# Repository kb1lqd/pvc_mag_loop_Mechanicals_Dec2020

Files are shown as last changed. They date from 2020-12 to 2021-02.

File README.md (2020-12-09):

# pvc_mag_loop_Mechanicals_Dec2020

This project is a work in progress as of 12-8-2020!
* Only the bottom clamp has been designed so far

This project is a FreeCAD design that is creating mounting bracket for my amateur radio magnetic loop antenna. The project implements the following sized components:

* Copper Pipe = 0.5"
* PVC Pipe = Schedule 40 2"

The design is fixed to these dimensions. Future update(s) may look to make this more scalable within FreeCAD using parametric links.

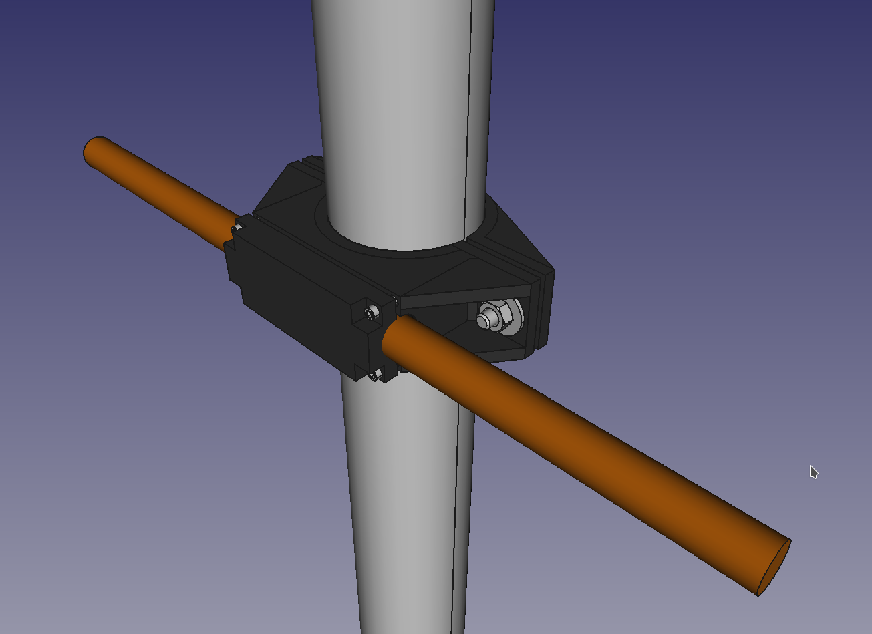
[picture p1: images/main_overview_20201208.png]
PVC to copper pipe magnetic loop adapter overview CAD image


## Known To-Do's

* Create top mount bracket
* Create capacitor mount bracket
* Create coupling loop bracket
* Update bottom clamp to show 4-40 threaded inserts
* Create BOM

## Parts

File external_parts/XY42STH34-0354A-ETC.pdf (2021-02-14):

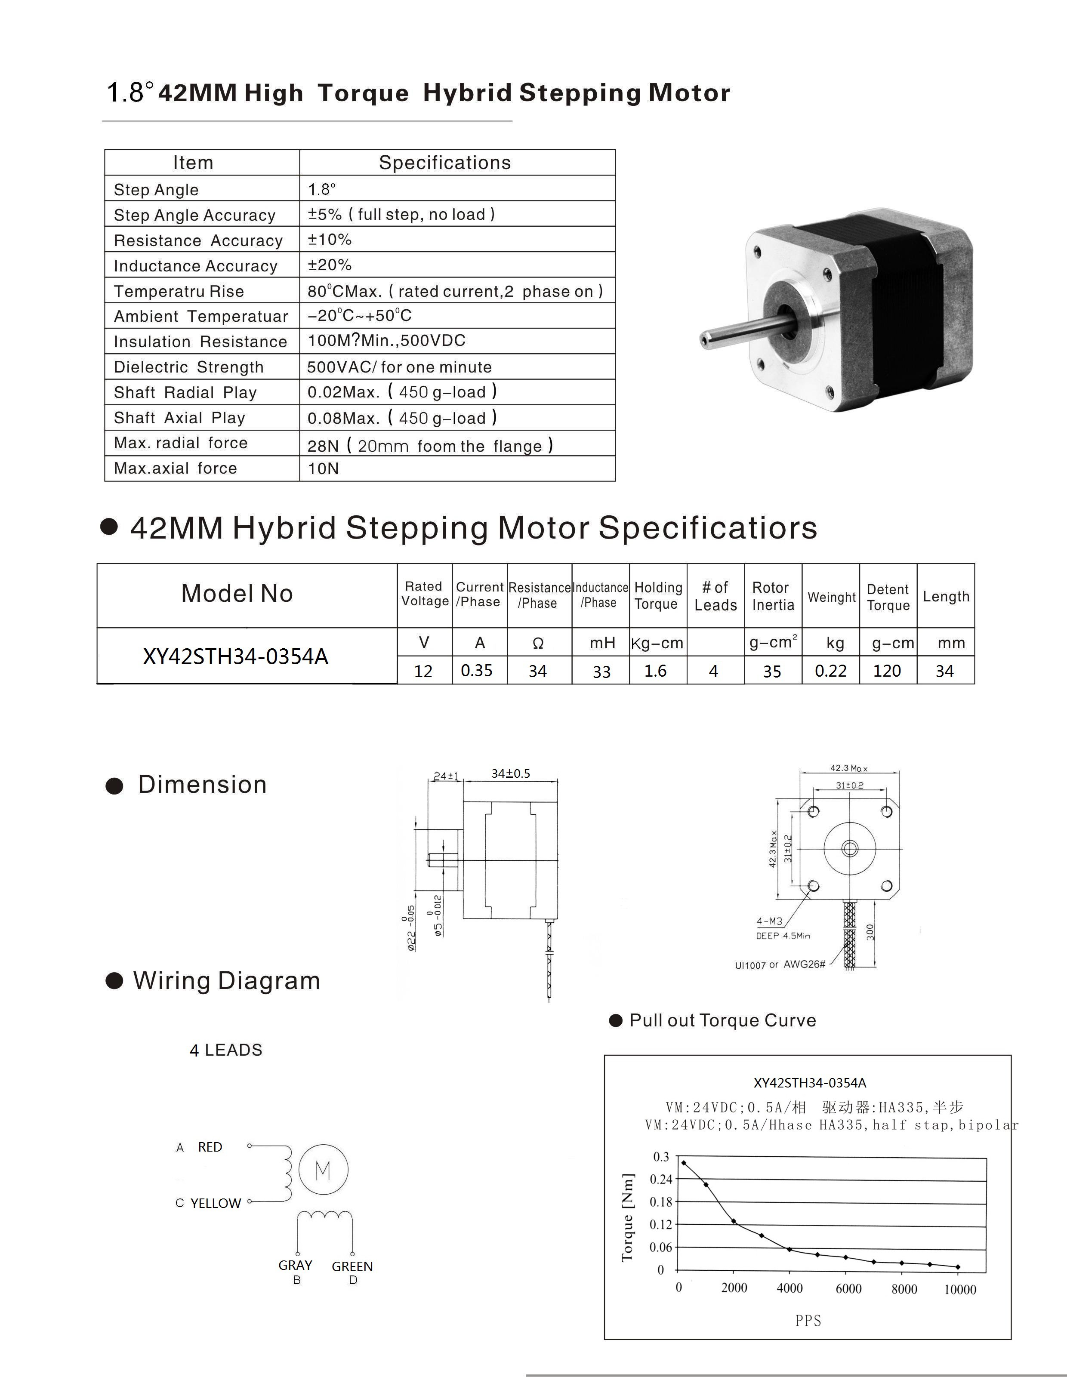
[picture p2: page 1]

07/03/2016 | C140-A datasheet.jpg (2480×3201)
https://www.adafruit.com/images/productfiles/324/C140-A%20datasheet.jpg | 1/1

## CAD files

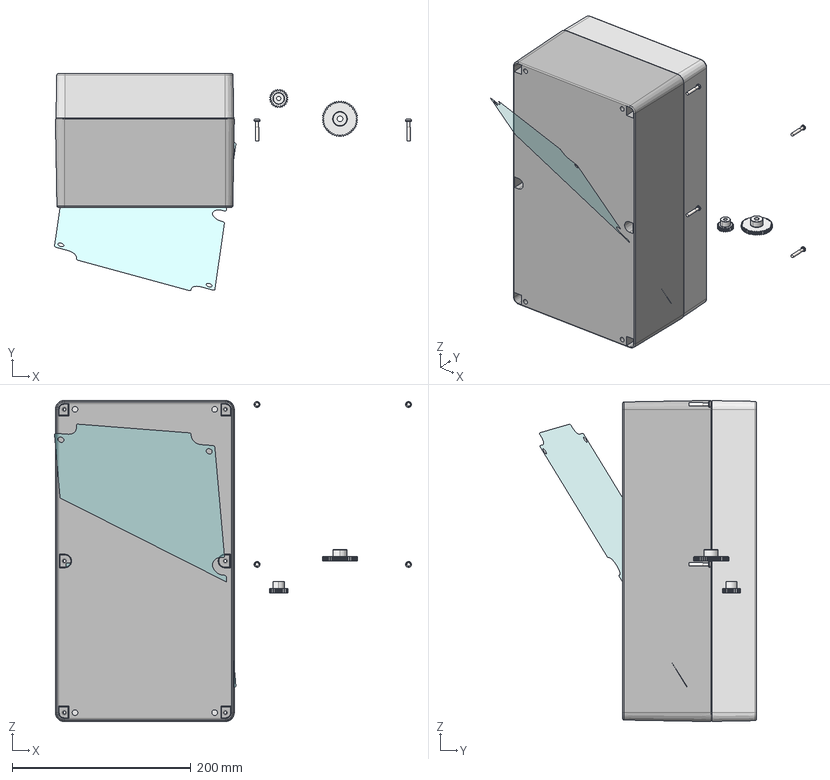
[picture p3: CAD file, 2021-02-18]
Version_3/capacitor_assembly_v1.FCStd
399.6 x 243.3 x 359.5 mm
W_-44B_WA-44B*16
SCREWS-SSM4-25
SCREWS-SSM4-026
SCREWS-SSM4-027
SCREWS-SSM4-028
SCREWS-SSM4-029
SCREWS-SSM4-030
W_-44C_WA-44C*16
W_-44B-PCB_WA-44B*16-PCB
2662N15
2662N18
_Element002
_Element003
_Element004
_Element005
_Element006
_Element007
_Element008
_Element009
_Element010
_Element011

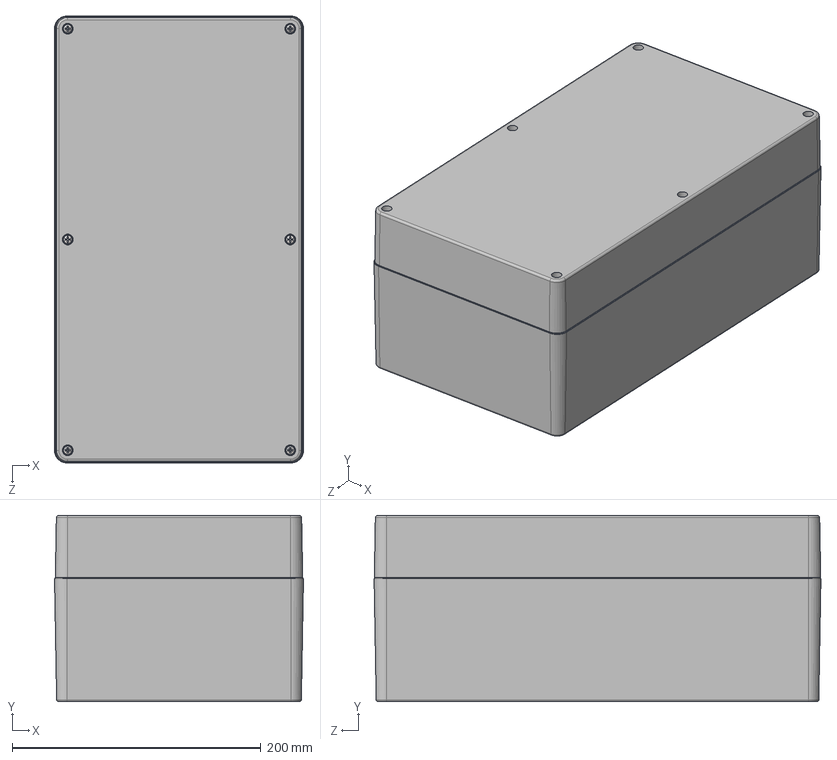
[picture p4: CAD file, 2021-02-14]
external_parts/WA-44.STEP
200.3 x 150.0 x 359.5 mm
W_-44B_WA-44B*16
SCREWS-SSM4-25 x 6
W_-44C_WA-44C*16
W_-44B-PCB_WA-44B*16-PCB

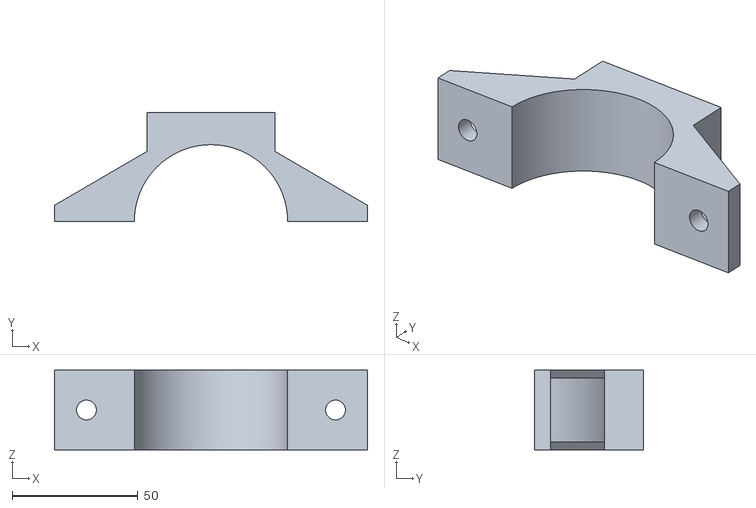
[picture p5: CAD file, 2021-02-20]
Version_3/pvc_box_mount_front_v1.stl
124.4 x 43.1 x 31.8

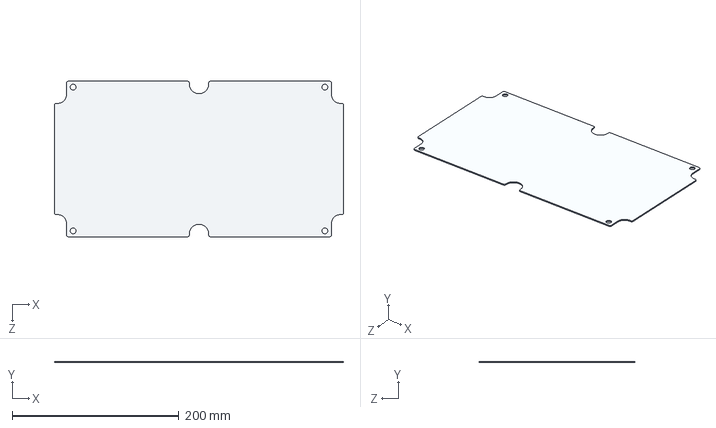
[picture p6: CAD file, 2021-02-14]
external_parts/WX-50P.STEP
346.7 x 1.50 x 186.6 mm

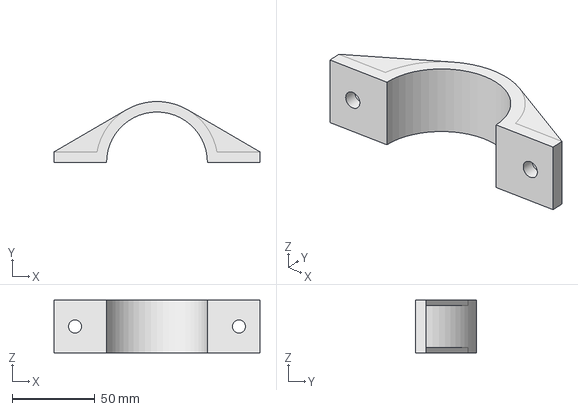
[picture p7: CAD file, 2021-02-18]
Version_3/pvc_clamp_cap_box_back_v1.FCStd
124.4 x 36.7 x 31.8 mm

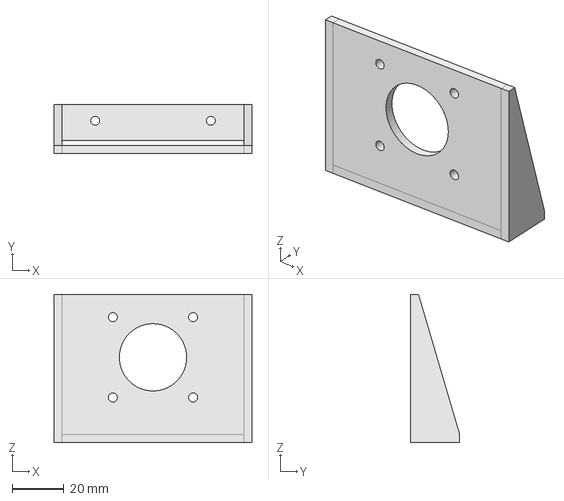
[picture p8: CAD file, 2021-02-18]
Version_3/nema_17_mount_v2.FCStd
76.5 x 19.1 x 57.1 mm

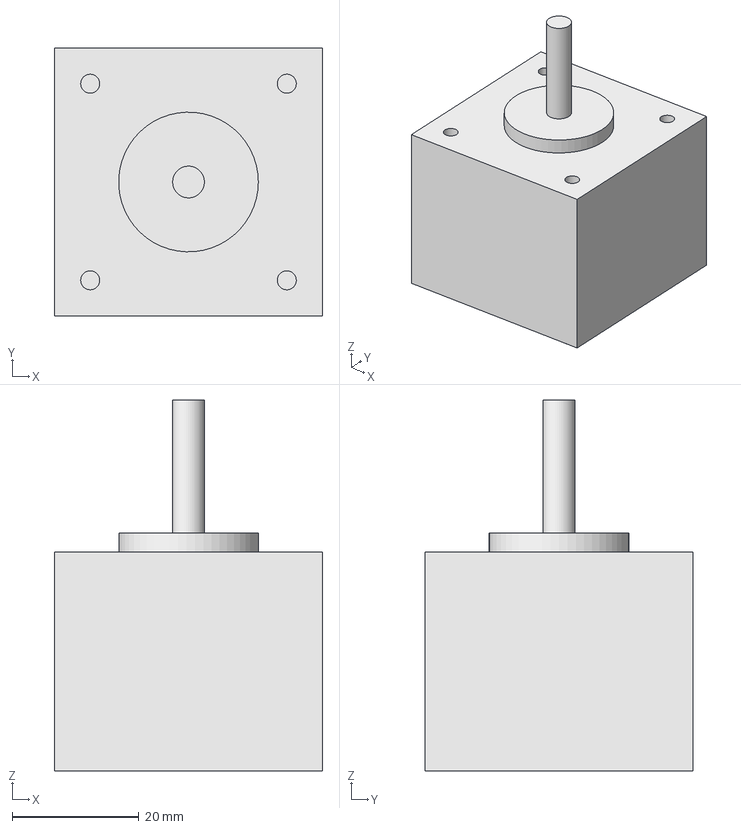
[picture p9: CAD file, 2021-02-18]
Version_3/nema_17_stepper_v1.FCStd
42.3 x 42.3 x 58.5 mm

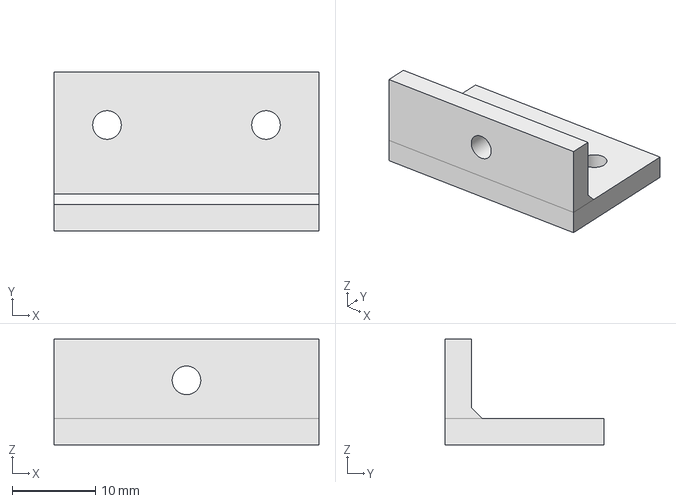
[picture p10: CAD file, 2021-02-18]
Version_3/capacitor_braket_v1.FCStd
31.8 x 19.1 x 12.7 mm

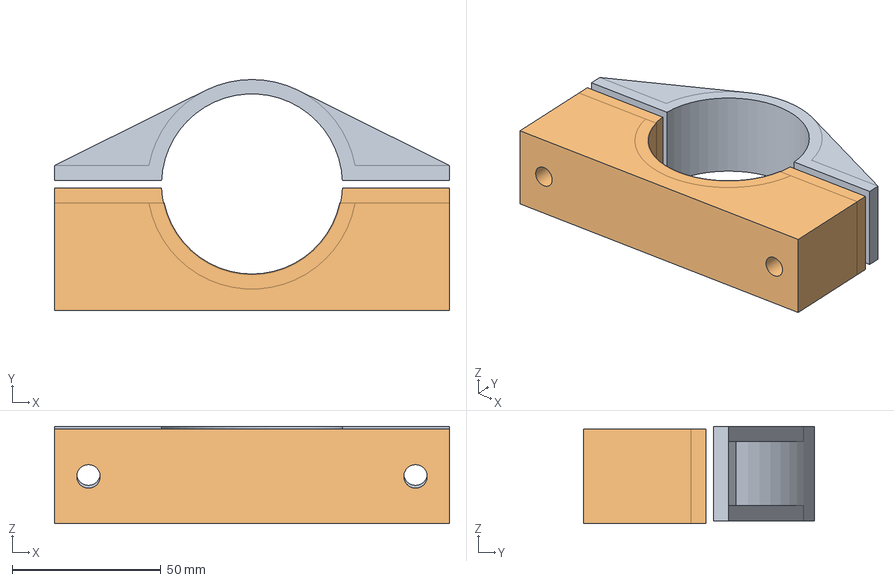
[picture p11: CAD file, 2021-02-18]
Version_3/Mag_Loop_PVC_Clamp-V3.FCStd
132.8 x 77.7 x 32.7 mm
CAPACITOR-BOX-CLAMP-BACK-TOP
CAPACITOR-BOX-CLAMP-FRONT-TOP

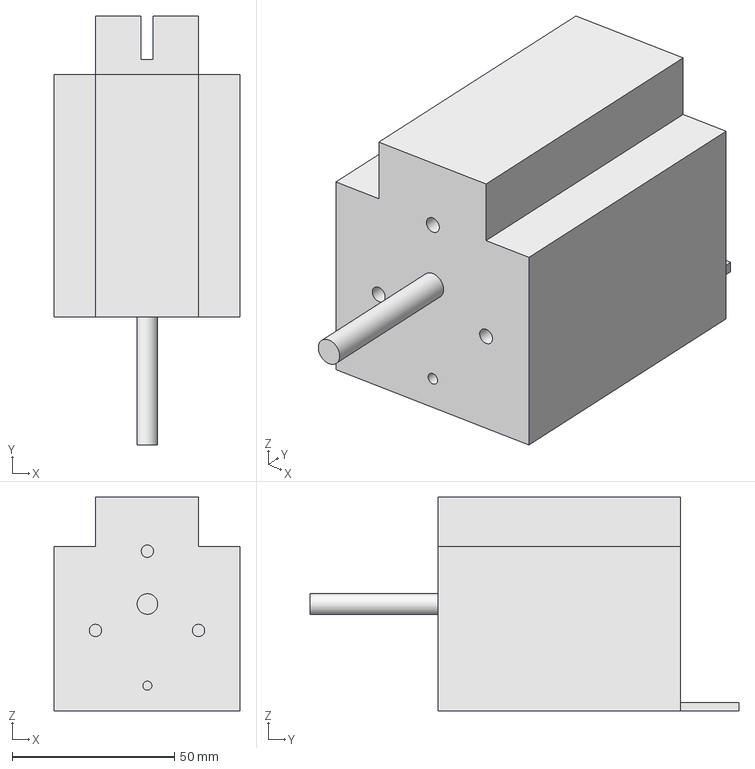
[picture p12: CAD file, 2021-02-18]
Version_3/variable_capacitor_v1.FCStd
57.1 x 132.1 x 65.8 mm

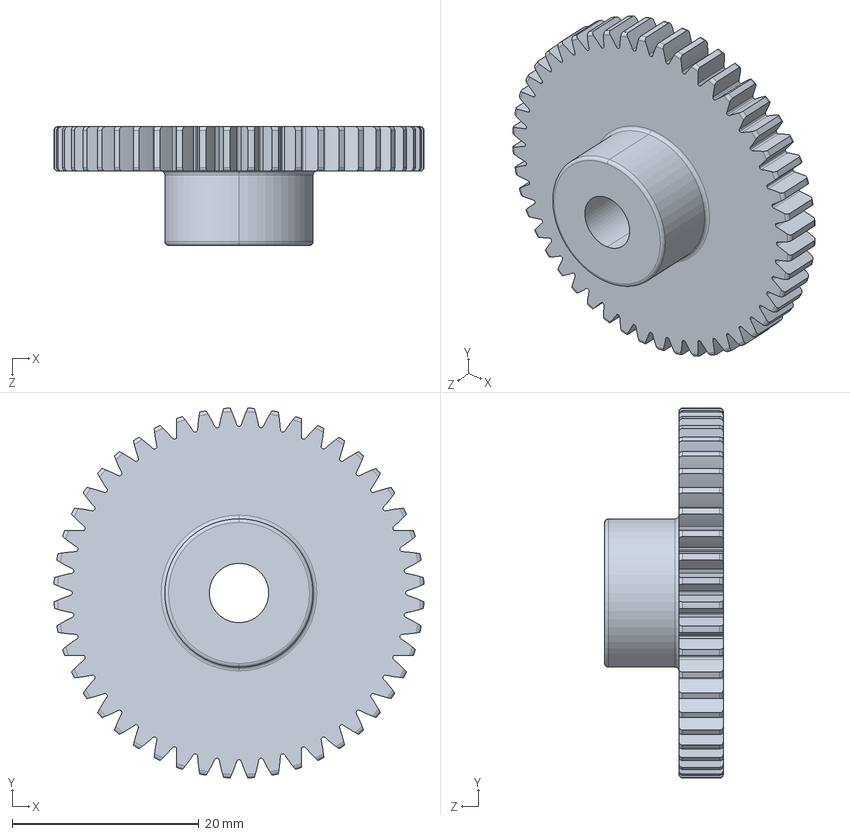
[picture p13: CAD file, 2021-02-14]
external_parts/2662N180_PLASTIC GEAR - 20 DEGREE PRESSURE ANGLE.STEP
39.6 x 39.6 x 12.7 mm

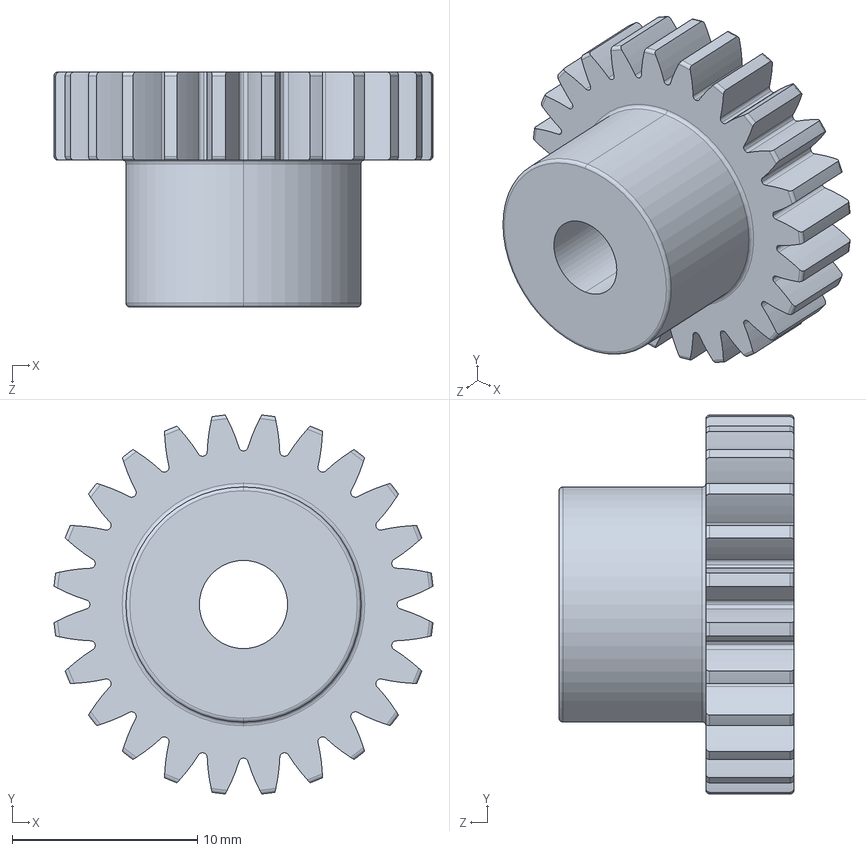
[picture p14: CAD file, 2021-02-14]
external_parts/2662N150_PLASTIC GEAR - 20 DEGREE PRESSURE ANGLE.STEP
20.5 x 20.5 x 12.7 mm

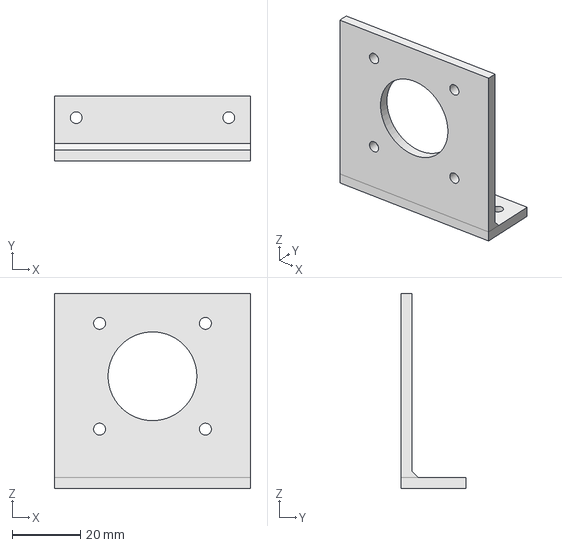
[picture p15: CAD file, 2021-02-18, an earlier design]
Deprecated/nema_17_mount_v1.FCStd
57.4 x 19.1 x 57.1 mm

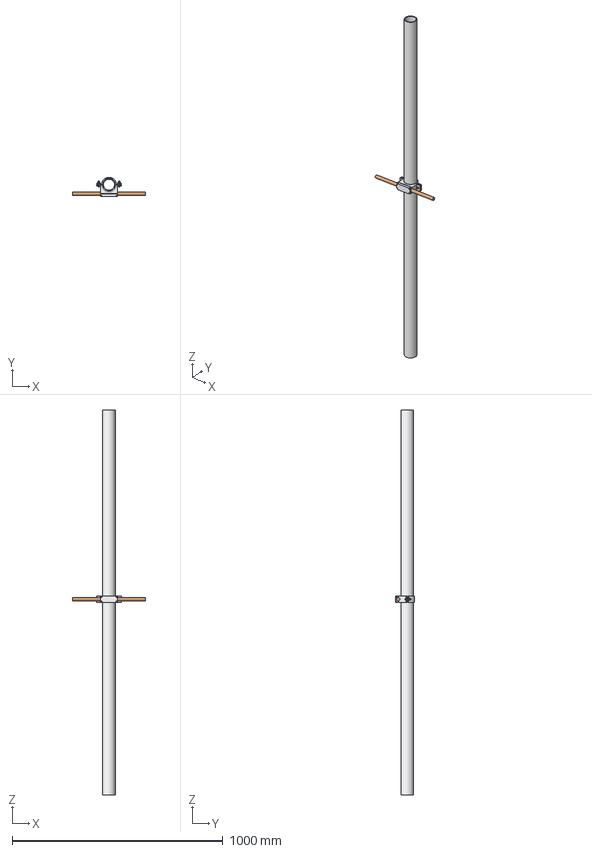
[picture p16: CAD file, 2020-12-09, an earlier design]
Deprecated/Version_1/Mag_Loop_PVC_Clamp-V1.FCStd
344.4 x 92.0 x 1828.8 mm
Clamp_Back
PVC
Bottom PVC Clamp With Cut
Clamp Front With Cut
Bottom Copper Pipe002
#4x1/2in-Screw
#4x1/2in-Screw004
#4x1/2in-Screw005
#4x1/2in-Screw006
1/4inx1in-Screw
1/4inx1in-Screw001
1/4in-Nut
1/4in-Washer
1/4in-Nut001
1/4in-Washer001

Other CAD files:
Deprecated/Version_2/Mag_Loop_PVC_Clamp-V2.FCStd
Version_2/Mag_Loop_PVC_Clamp-V2.FCStd

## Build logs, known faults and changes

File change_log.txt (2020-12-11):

Version 1
* Initial baseline

Version 2
---12-7-2020---

Top Cover
* Changed color to an off black
* Increased 4-40 hole from 72 thou radius to 80 thou
** Found that the lower right hole was 70 not 72 thou which explains the single very tight hole!
* Changed copper pipe cutout from subtractive part to parameteric.

Main Front Clamp
* Changed color to an off black
* Increased PVC tab to 1.25" to give room for washers
* Increased 1/4 holes from radius 0.1285" to 0.1555" to reach 0.311" diameter loose clearance
** I also think I may be able to improve dimensions by adjusting CURA estimated PLA shrinkage.
* Updated copper pipe radius cutout to face pocket parametric rather than subrative part workbench.
* Added 100 thou chamfer to the fastener legs to main body to reduce stress riser (May not be needed with below addition of supports)
* Added 200 thou dual supports to bolt mounts and main support body

Back Clamp
* Changed color to an off black
* Increased PVC tab to 1.25" to give room for washers and match main front clamp
* Increased 1/4 holes from radius 0.1285" to 0.1555" to reach 0.311" diameter loose clearance
* Added tangental bolt supports of 200 thou on each side to support the bolt mount
* Added 100 thou chamfer to to bolt to pvc curve to reduce stress risers (may not be needed with above supports)

Version 3
------
General
* Created octagon copper pipe for mag loop
* Moved bottom clamp parts down to bottom of octagon
* Found bottom cover copper cutout was only through half of part, fixed.

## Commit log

2020-12-09 Adding initial commit with version 2 updates.
    [Mag_Loop_PVC_Clamp-V1.FCStd, Mag_Loop_PVC_Clamp-V2.FCStd]
2020-12-11 Moving to Version 3.
    [Mag_Loop_PVC_Clamp-V2.FCStd, Mag_Loop_PVC_Clamp-V3.FCStd]
2020-12-27 Made quick version of top clamp.
    [Mag_Loop_PVC_Clamp-V3.FCStd]
2021-02-14 Adding external components, assembly workbench, and created a basic model of the nema 17 stepper motor.
    [2662N150_PLASTIC GEAR - 20 DEGREE PRESSURE ANGLE.STEP, 2662N180_PLASTIC GEAR - 20 DEGREE PRESSURE ANGLE.STEP, Mag_Loop_PVC_Clamp-V3.FCStd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]
2021-02-14 Adding brackets.
    [Mag_Loop_PVC_Clamp-V3.FCStd, capacitor_assembly.FCStd, capacitor_braket.FCStd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]
2021-02-18 Updating files to version names.
    [Mag_Loop_PVC_Clamp-V3.FCStd, capacitor_assembly.FCStd, capacitor_assembly_v1.FCStd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]
2021-02-18 Creating version 2 of nema 17 bracket.
    [nema_17_mount_v1.FCStd, nema_17_mount_v2.FCStd]
2021-02-18 Updated to version 2 bracket with supports.
    [nema_17_mount_v2.FCStd]
2021-02-18 Fixed linear pattern distance error. Added wall thickness variable.
    [nema_17_mount_v2.FCStd]
2021-02-18 Adding new, single part, parametric PVC Clamp.
    [pvc_clamp_cap_box_v1.FCStd]
2021-02-20 Adding new front mount
    [pvc_box_mount_front_v1.stl]
2021-02-20 Changing from 0.25 inch inserts to M4.
    [pvc_box_mount_front_v1.stl]
